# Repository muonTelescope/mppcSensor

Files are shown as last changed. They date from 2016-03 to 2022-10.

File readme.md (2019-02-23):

# MPPC Sensor
The sensor board has just the MPPC and a coaxial connector to feed in the high voltage and inside shielding pull the signal out. There are two mounting holes on the sides and the board is designed to be small and mounted inside a plastic carrier. An ambient temperature sensor is required to set the voltage but is not provided on the board, as the gain is dependent on temperature and bias voltage, a constant gain can be maintained by changing the bias in response to temperature.

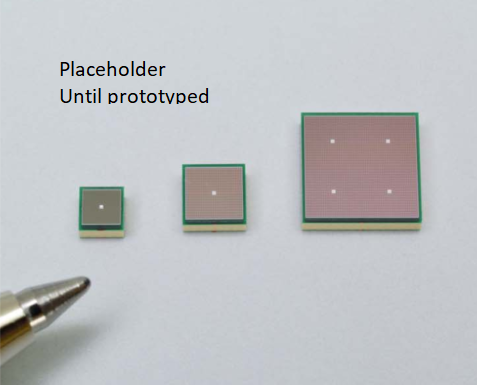
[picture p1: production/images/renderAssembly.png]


## Hardware
This board houses a surface mount 2.0mm MPPC by Hamamatsu. Specifically, S13360-20**VE series. Both ports are routed directly out to the connector. The board is  0.25in (6.35) tall, 0.5in (12.7mm) wide and approximately XXin deep. It is attached to the housing with two M2 screws. 

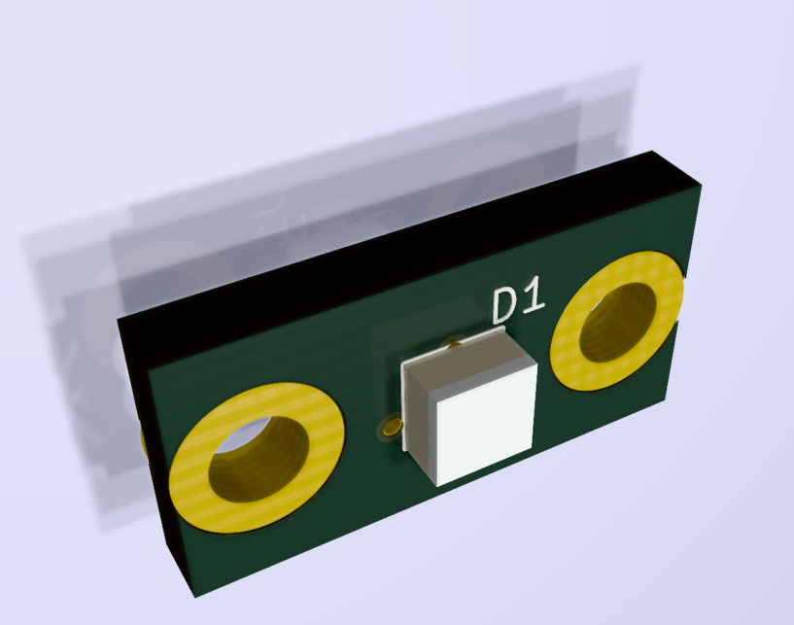
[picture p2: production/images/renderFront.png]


## Cable
A U.FL coaxial connector is mounted on the back. It is rated for 50 mattings. HV is brought in through shielding (connected to cathode) and should be insulated. signal is returned (anode) through the inner conductor. The connector and the board have no polarity.

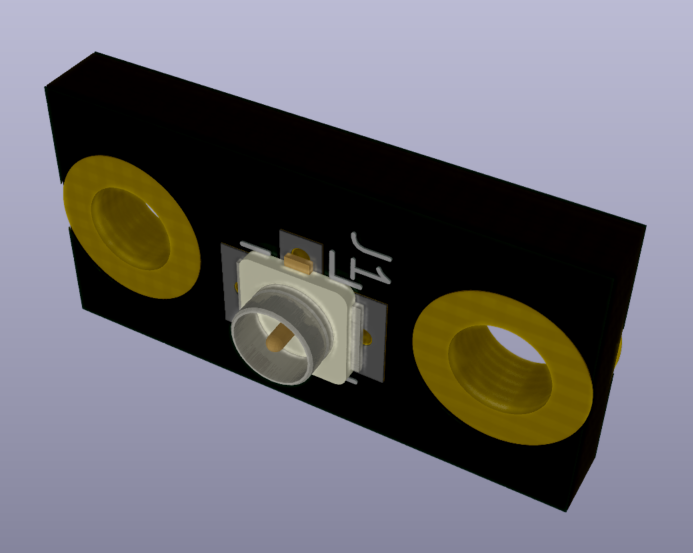
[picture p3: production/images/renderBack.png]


## Housing
Housing is designed in Autodesk inventor, more info later.

## Fabrication/Assembly
Documents such as gerbers, PNP, BOM, STL, images and renderings are availible in the `production` directory.

The PCB is a two sided 63mil (1.6mm) with 6/6 routing. Front and back silk and soldermask is not needed but prefered. Assembly requires PNP on two sides, but ideally should be done manually. The MPPC should be handeled delicately and its part number and parameters should be kept. After assembly place the part back in its original bag. 

### Front PCB
Only MPPC on front with though mounting holes shown. The polarity is shown with the notch visible at the bottom. 
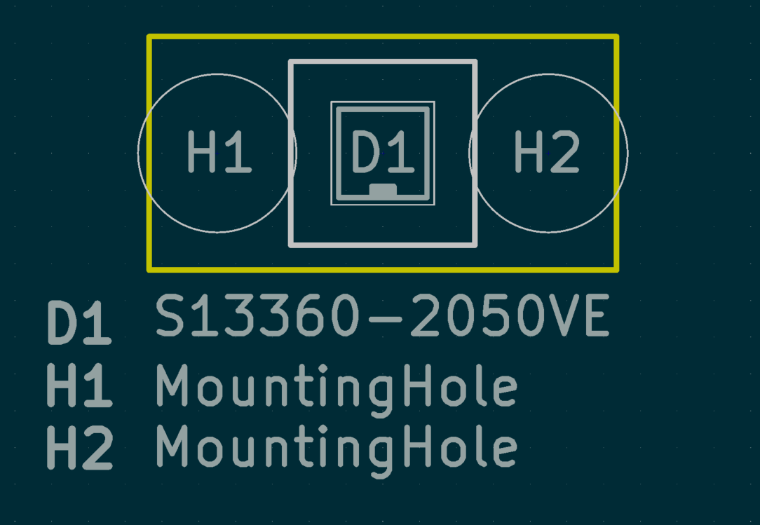
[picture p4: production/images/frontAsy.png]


### Back PCB
Back has only the U.FL connector. There is only one polarity but since there are two tabs generally available on the connectors the bottom must be ckeced or the pin one cut corner to determine orientation.
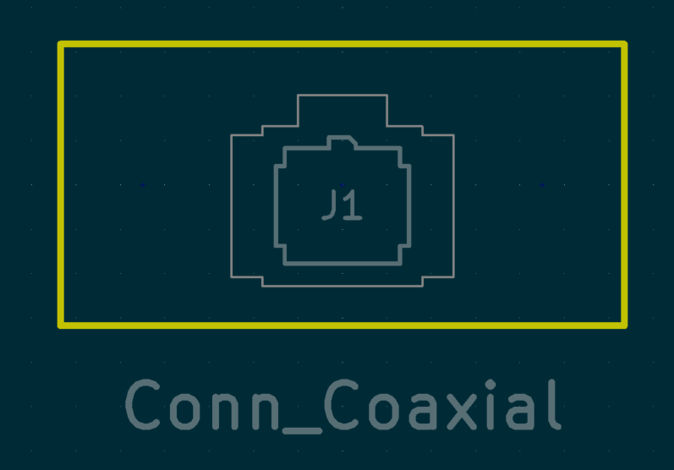
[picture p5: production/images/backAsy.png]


### Soldering
Solder the back first (reflow or by hand) before placing and reflowing the MPPC, surface tension should be enough to hold in place for the reflow, but CA can be applied to make sure it does not shift. The MPPC ideally should be reflowed with the Hamamatsu temperature profile.
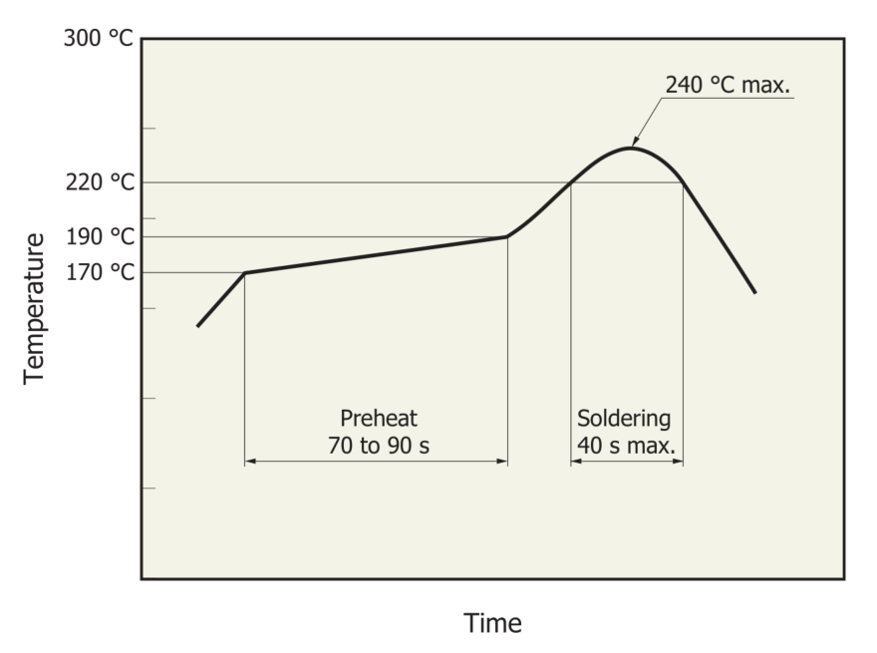
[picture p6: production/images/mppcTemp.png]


### Housing
The housing is to be made form a opaque material. Can be 3D printed or IM (if design permits). More infor after design.

[renderAssembly]: production/images/renderAssembly.png "Full assembly permutations inculding housings."
[renderFront]: production/images/renderFront.png "Assembled board front render showing MPPC."
[renderBack]: production/images/renderBack.png "Assembled board back render showing connector."
[frontAsy]: production/images/frontAsy.png "Component location and markings for front."
[backAsy]: production/images/backAsy.png "Assembled board back render showing connector."
[mppcTemp]: production/images/mppcTemp.png "Reflow temperature profile for Hamamatsu MPPC from datasheet."

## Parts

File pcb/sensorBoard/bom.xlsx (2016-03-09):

Ref-Des | Function | Description | P/N | Digikey P/N | QTY | Unit Price | Extended Price | URL
C1,C3,C4,C5 | Decoupling/Low-Pass | CAP CER 0.1UF 25V X6S 0201 | GRM033C81E104ME14D | 490-10404-1-ND | 4 | $0.02310 | $0.09 | http://www.digikey.com/scripts/DkSearch/dksus.dll?Detail&itemSeq=191776716&uq=635931346694799446
C2 | Common Mode Decoupling | CAP CER 10000PF 25V X5R 0201 | CC0201KRX5R8BB103 | 311-1598-1-ND | 1 | $0.00720 | $0.01 | http://www.digikey.com/scripts/DkSearch/dksus.dll?Detail&itemSeq=191776703&uq=635931346694799446
C6 | Power Low-Pass | CAP CER 0.047UF 25V X5R 0201 | C0603X5R1E473K030BB | 445-13679-1-ND | 1 | $0.02750 | $0.03 | http://www.digikey.com/scripts/DkSearch/dksus.dll?Detail&itemSeq=191776730&uq=635931346694809447
C7 | Decoupling | CAP CER 1UF 10V X5R 0603 | CL10A105KP8NNNC | 1276-1182-1-ND | 1 | $0.01400 | $0.01 | http://www.digikey.com/scripts/DkSearch/dksus.dll?Detail&itemSeq=191776739&uq=635931346694809447
C8 | Decoupling | CAP CER 10UF 10V X5R 0603 | GRM188R61A106ME69D | 490-10475-1-ND | 1 | $0.06560 | $0.07 | http://www.digikey.com/scripts/DkSearch/dksus.dll?Detail&itemSeq=191776695&uq=635931346694799446
D1 | MPPC | 1.3x1.3mm MPPC | S13360-1375PE | S13360-1375PE | 1 | $22.00000 | $22.00 | http://www.hamamatsu.com/eu/en/product/new/S13360-1375PE/index.html
D2 | Led | LED UV/NUV 380NM 200MW FLIPCHIP | L1F2-U380100002001 | 1416-1494-1-ND | 1 | $4.24200 | $4.24 | http://www.digikey.com/scripts/DkSearch/dksus.dll?Detail&itemSeq=191777383&uq=635931346694829449
J1,J2 | Spring Connector | BATTERY CONN 1.2H 1.6MM DR 4CKT | 788640001 | WM11203CT-ND | 2 | $0.25470 | $0.51 | http://www.digikey.com/scripts/DkSearch/dksus.dll?Detail&itemSeq=191781778&uq=635931369481427881
R1,R4 | Op-amp Feedback | RES SMD 10K OHM 0.1% 1/20W 0201 | ERA-1AEB103C | P10KBXCT-ND | 1 | $0.13330 | $0.13 | http://www.digikey.com/scripts/DkSearch/dksus.dll?Detail&itemSeq=191777143&uq=635931346694819448
R2 | NTC Therm | THERMISTOR NTC 100KOHM 0.5% 0603 | NCP18WF104D03RB | 490-11811-1-ND | 1 | $0.31270 | $0.31 | http://www.digikey.com/scripts/DkSearch/dksus.dll?Detail&itemSeq=191777258&uq=635931346694829449
R3 | 50 ohm Term | RES SMD 51 OHM 5% 1/20W 0201 | RC0201JR-0751RL | 311-51NCT-ND | 1 | $0.01660 | $0.02 | http://www.digikey.com/scripts/DkSearch/dksus.dll?Detail&itemSeq=191777089&uq=635931346694819448
R5,R6 | Op-amp Gain | RES SMD 100 OHM 0.1% 1/20W 0201 | ERA-1AEB101C | P100BXCT-ND | 2 | $0.13330 | $0.27 | http://www.digikey.com/scripts/DkSearch/dksus.dll?Detail&itemSeq=191777165&uq=635931346694829449
R7 | Power Low-Pass | RES SMD 10 OHM 5% 1/20W 0201 | RMCF0201JT10R0 | RMCF0201JT10R0CT-ND | 1 | $0.01620 | $0.02 | http://www.digikey.com/scripts/DkSearch/dksus.dll?Detail&itemSeq=191777080&uq=635931346694809447
R8 | Power Low-Pass | RES SMD 1K OHM 5% 1/20W 0201 | RC0201JR-071KL | 311-1KNCT-ND | 1 | $0.01660 | $0.02 | http://www.digikey.com/scripts/DkSearch/dksus.dll?Detail&itemSeq=191777087&uq=635931346694819448
U1 | Op-Amp | IC AMP/DRIVER DIFF 10-QFN | LTC6409CUDB#TRMPBF | LTC6409CUDB#TRMPBFCT-ND | 1 | $8.85100 | $8.85 | http://www.digikey.com/scripts/DkSearch/dksus.dll?Detail&itemSeq=191775856&uq=635931346694789445
J3 | Ouptut Header | CONN HEADER 2MM DUAL SMD 8POS | NRPN042MAMS-RC | S6009-04-ND | 1 | $0.58200 | $0.58 | http://www.digikey.com/scripts/DkSearch/dksus.dll?Detail&itemSeq=191766851&uq=635931369481377876
J3-F | Output Header Jack | CONN IDC SOCKET 8POS 2MM GOLD | 89361-708LF | 609-3140-ND | 1 | $1.08800 | $1.09 | http://www.digikey.com/scripts/DkSearch/dksus.dll?Detail&itemSeq=191766263&uq=635931369481367875

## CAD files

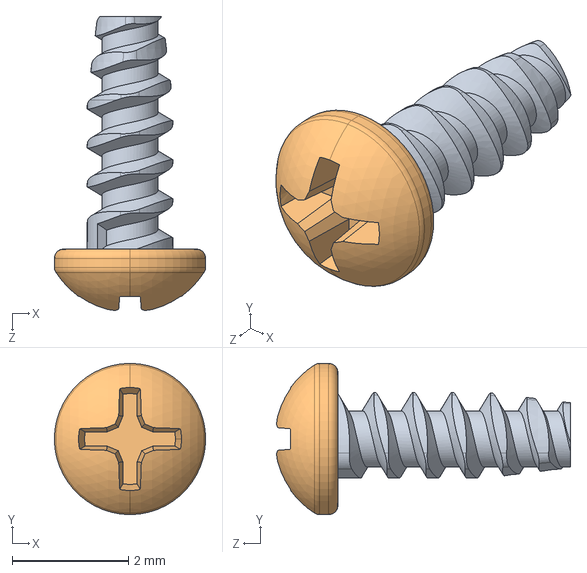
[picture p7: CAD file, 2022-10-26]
pcb/components/M1.6/M1.6x4-Pan-Plastic.step
2.60 x 2.60 x 5.06 mm

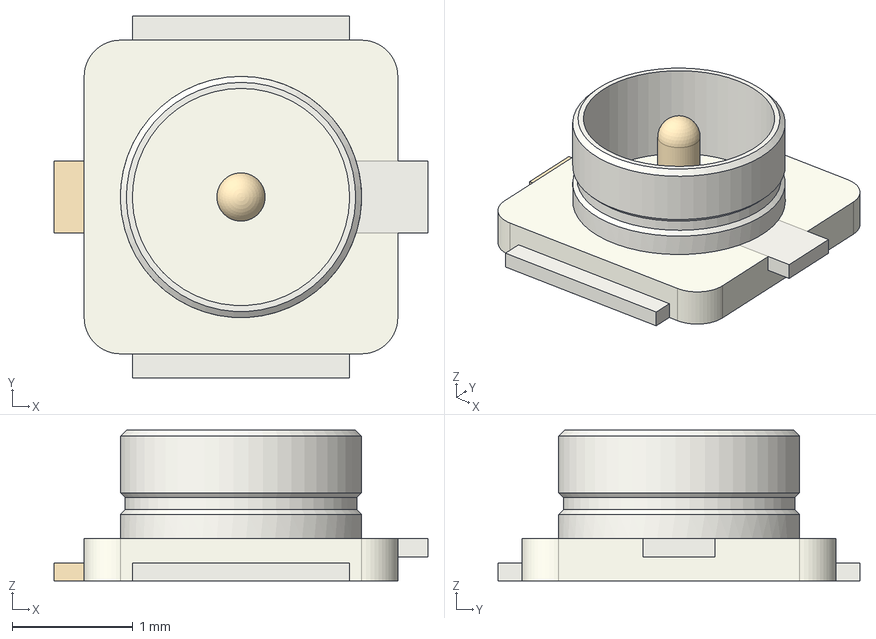
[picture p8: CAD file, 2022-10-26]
pcb/components/U.FL/U.FL.step
3.10 x 3.00 x 1.25 mm

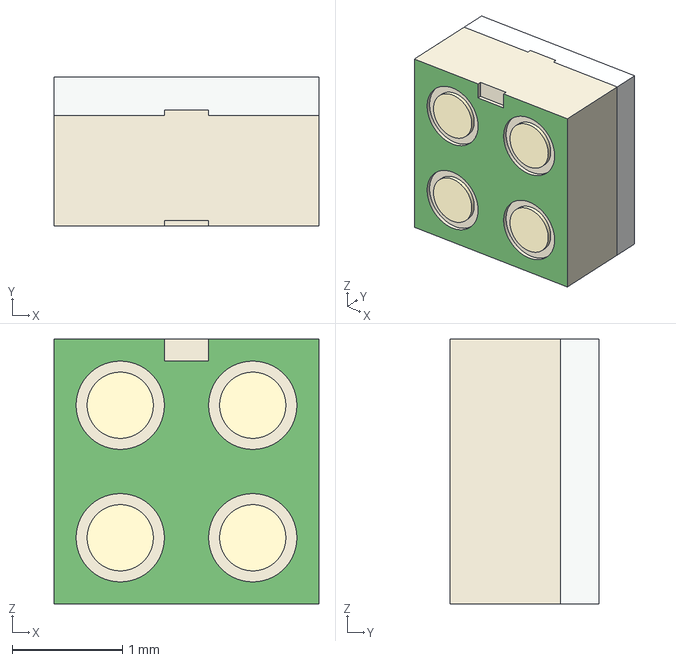
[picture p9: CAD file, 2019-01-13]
pcb/components/s13360-2050ve/s13360-2050ve.stp
2.40 x 1.35 x 2.40 mm

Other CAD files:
cad/sensor.iam

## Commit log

2015-09-09 Added more files
    [BOM.xlsx]
2015-09-09 Deleted V1,2,3
    [BOM.xlsx]
2015-09-09 Remove V5
    [BOM.xlsx]
2015-09-09 Removed files, and reorganised file system.
    [bom.xlsx]
2015-09-09 Added cad files
    [0805 Capacitor.ipt, 0805.ipt, 128-0711-201.ipt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]
2015-09-09 Added cad data
    [MPPC.ipt, pcbV3.ipt, pcbV4.ipt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]
2015-09-09 Only left v4 cad data
    [pcb.ipt, pcbV3.ipt, pcbV5.ipt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]
2015-09-09 Refreshed file name and locations
    [pcb.ipt, sensor.iam]
2015-10-09 No idea what changed
    [pcb.ipt, sensor.iam]
2015-10-09 Resaved files
    [pcb.ipt, sensor.iam]
2015-10-15 Added pattren files, rebuit sensor to use modular jackes.
    [pcb.ipt, sensor.iam]
2015-10-16 New Cad model
    [0805 Capacitor.ipt, 0805.ipt, 128-0711-201.ipt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]
2015-10-16 Moved cap file
    [capacitor-0402.ipt]
2015-10-16 Moved mounting holes down
    [MPPC.iam, pcb.ipt]
2015-11-05 Edge connector layout final
2015-11-05 Cad desgin done, only ethernet jack left
    [capacitor-0402.ipt, capacitor.ipt, pcb.ipt]
2015-11-05 Cad desgin done, only ethernet jack left, parts added
    [MOLEX_0955012882.STEP, MOLEX_0955012882.ipt, S3O8.ipt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]
2015-11-06 3d files added
    [ethernetBoard.step, hv.iam, jumper.iam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]
2015-11-09 Fixed bom
    [bom.xlsx]
2015-11-09 single rail amp, themistor voltage readout
    [bom.xlsx]
2015-11-09 SMD MPPC, 7mm wide pcb
2015-11-13 Fixed BOM errors, pcb approx postioning/sizing done
    [bom.xlsx]
2016-01-19 Seperate 60V supply
2016-01-20 Max1932 Power section
2016-01-20 Headers added, Custom power supply complete
2016-01-23 MOved temp resistor off, moved vias arround
2016-01-25 Compact assembly
2016-01-25 Reduced size, re organised connectors
2016-01-25 Finished routing attachment pcb
2016-02-15 Cad done
    [L1F2-U.ipt, MOLEX_0955012882.STEP, MOLEX_0955012882.ipt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]
2016-02-17 Added Haeader
    [2x4RibbonConnector.ipt, 2x4header.ipt, boardB.iam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]
2016-02-23 Interface board desgin started
    [pcb.ipt, sensorBoard.iam]
2016-02-27 Switching branches
    [bom.xlsx]
2016-03-02 Sent out to fab
    [MPPC.iam, bom.xlsx]
2016-03-09 BOM Updated
    [bom.xlsx]
2016-03-26 Removed old files
    [bom.xlsx]
2016-03-27 Moved interface Board to its own repo
    [bom.xlsx]
2016-03-28 this one has the 3mm sensor
    [13360-30xxPE.iam, 788640001.iam, boardB.iam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]
2016-03-28 Fixed the mppc type
    [13360-30xxPE.iam, 788640001.iam, S13360-13xxPE.iam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]
2016-03-28 Renamed from sensotboard
    [boardC.iam, capacitor-0603.ipt, mppcSensor.iam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]
2016-04-02 Revert to use older Op-Amp
    [bom.xlsx]
2016-06-15 Removed spacer rubber
    [boardB.iam, boardC.iam, mppcSensor.iam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]
2017-01-05 Rebuilt, bom still needs to be fixed.
    [13360-30xxVE.ipt, 2x4RibbonConnector.ipt, 2x4header.ipt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]
2017-01-07 BOM fixed, REF-DES cahnged for led
    [bom.xlsx]
2019-01-13 inital commit
    [mppcSensor.kicad_pcb, mppcSensor.sch, s13360-2050ve.ipt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]
2019-02-23 Changed to kicad, sensor only boards
    [13360-30xxVE.ipt, 788640001.iam, 788640001.ipt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]
2019-02-23 Moved files to pcb folder
    [mppcSensor.kicad_pcb, mppcSensor.sch, s13360-2050ve.ipt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]
2019-02-23 Updated readme with new design, added renderings.
    [mppcSensor.kicad_pcb]
2019-02-23 Added cad dir
    [s13360-2050ve.ipt, ufl.ipt]
2022-10-26 oldBoard snapshot
    [mppcSensor - OSH.kicad_pcb, mppcSensor - OSHPark.kicad_pcb, mppcSensor.sch]
2022-10-26 Removed old files updated libraries
    [M1.6x4-Pan-Plastic.step, U.FL.step, mppcSensor - OSH.kicad_pcb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]
2022-10-26 Modified board to oshpark req .25x.25
    [mppcSensor.kicad_pcb]
